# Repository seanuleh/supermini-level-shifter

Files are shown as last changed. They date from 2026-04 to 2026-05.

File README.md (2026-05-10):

# Hyper Level Shifter

A simple through-hole PCB that pairs an ESP32-S3 Super Mini with a SN74AHCT125N quad bus buffer to shift 3.3V GPIO signals up to 5V logic — designed for driving WS2812B/SK6812 LED strips with [Hyperk](https://github.com/awawa-dev/Hyperk) / [HyperHDR](https://github.com/awawa-dev/HyperHDR) ambilight setups.

<table><tr>
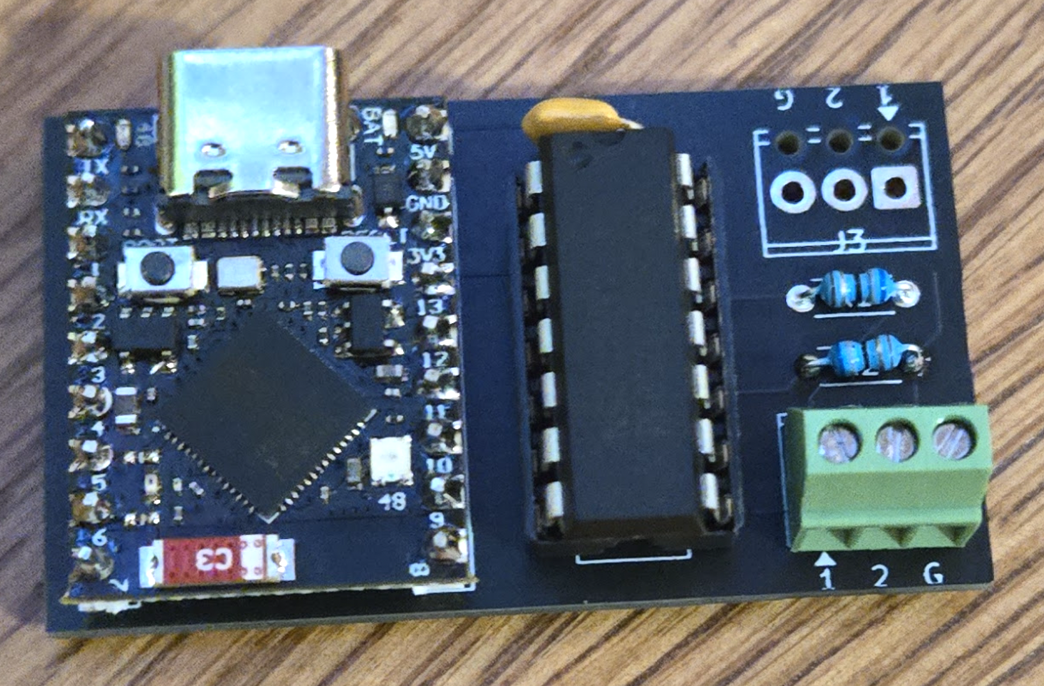
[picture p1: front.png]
PCB Front
<td></td>
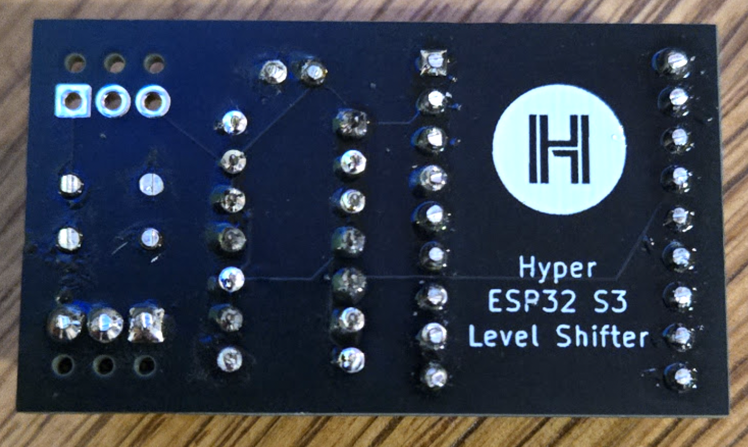
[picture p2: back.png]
PCB Back
<td></td>
</tr><tr>
<td align="center">Front</td>
<td align="center">Back</td>
</tr></table>

**[Download Gerbers (ZIP)](https://github.com/seanuleh/supermini-level-shifter/raw/main/manufacturing/default/default.gerber.zip)** — ready for JLCPCB / PCBWay (order bare PCB only)

## Features

- Socket for ESP32-S3 Super Mini (2× 1×9 female 2.54mm headers)
- DIP-14 socket for SN74AHCT125N logic level shifter (3.3V → 5V)
- Dual 3-pin 2.54mm screw terminals (top + bottom — choose whichever orientation suits your wiring)
- 68Ω series resistors on data outputs for signal integrity
- 100nF decoupling capacitor on IC VCC
- All through-hole components — no SMD soldering required

## Screw Terminal Pinout

Both terminals are electrically identical:

| Pin | Signal | Description |
|-----|---|---|
| 1 | DATA1  | GP1 level-shifted (5V logic) — LED segment 1 |
| 2 | DATA2  | GP2 level-shifted (5V logic) — LED segment 2 |
| 3 | GND | Ground reference |

> Power (5V) for the LED strips should come from a dedicated 5V supply, not the ESP32.

## Signal Path

```
ESP32 GP1 (3.3V) → SN74AHCT125N 1A → 1Y → 68Ω → Terminal pin 1
ESP32 GP2 (3.3V) → SN74AHCT125N 2A → 2Y → 68Ω → Terminal pin 2
ESP32 GND ──────────────────────────────────────→ Terminal pin 3
ESP32 5V  ──────────────────────────────────────→ IC VCC (pin 14)
```

## BOM

All parts are hand-soldered. No JLCPCB assembly required — order the bare PCB only.

| Ref | Part | Notes |
|-----|---|---|
| J1, J2 | 1×9 female 2.54mm pin header | 2× required |
| U1 | SN74AHCT125N | DIP-14, e.g. LCSC C5907 |
| — | DIP-14 IC socket | Order separately |
| J3, J4 | 3-pin 2.54mm screw terminal | e.g. KF128-2.54-3P, Phoenix MPT-0.5/3-2.54 |
| R1, R2 | 68Ω 1/8W axial resistor | Any 62–100Ω 1/8W axial |
| C1 | 100nF ceramic disc capacitor | 50V, 2.5mm pitch |

## Assembly Notes

- Install the DIP-14 socket first, then insert the SN74AHCT125N IC into the socket
- ESP32-S3 Super Mini plugs into J1/J2 with USB-C port facing toward the "USB Port ↑" silkscreen label
- The decoupling cap (C1) is non-polarised — orientation doesn't matter
- LED strip power should come from a dedicated 5V PSU; the ESP32 5V pin cannot source enough current for a full TV ambilight run

## Project Structure

Built with [atopile](https://atopile.io) 0.15.x.

```
ato.yaml                        # Build config
elec/src/
  level_shifter.ato             # Top-level module
  esp32s3_super_mini.ato        # ESP32 socket module
  parts/
    Header1x9F/                 # 1×9 female header
    SN74AHCT125N/               # DIP-14 quad buffer
    ScrewTerminal_2.54_3P/      # 3-pin screw terminal
    Resistor_TH_68R/            # 68Ω axial resistor
    Capacitor_TH_100nF/         # 100nF ceramic disc cap
elec/layouts/default/           # KiCAD PCB layout
```

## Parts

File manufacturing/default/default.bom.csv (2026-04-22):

Designator | Footprint | Quantity | Value | Manufacturer | Partnumber | LCSC Part #
C1 | Capacitor_TH_100nF:C_Disc_D3.0mm_W1.6mm_P2.50mm | 1 |  | Generic | C_100nF_TH_50V | CNONE_C100NF_TH
J1, J2 | Header1x9F:PinSocket_1x09_P2.54mm_Vertical | 2 |  | Generic | PinSocket_1x09_2.54mm | CNONE_HDR1X9F
J3, J4 | ScrewTerminal_2.54_3P:TerminalBlock_Phoenix_MPT-0,5-3-2.54_1x03_P2.54mm_Horizontal | 2 |  | Generic | ScrewTerminal_2.54mm_3P | CNONE_SCREW3P254
R1, R2 | Resistor_TH_68R:R_Axial_DIN0204_L3.6mm_D1.6mm_P5.08mm_Horizontal | 2 |  | Generic | R_68R_TH_1/8W | CNONE_R68R_TH
U1 | SN74AHCT125N:DIP-14_W7.62mm | 1 |  | Texas Instruments | SN74AHCT125N | CNONE_SN74AHCT125N

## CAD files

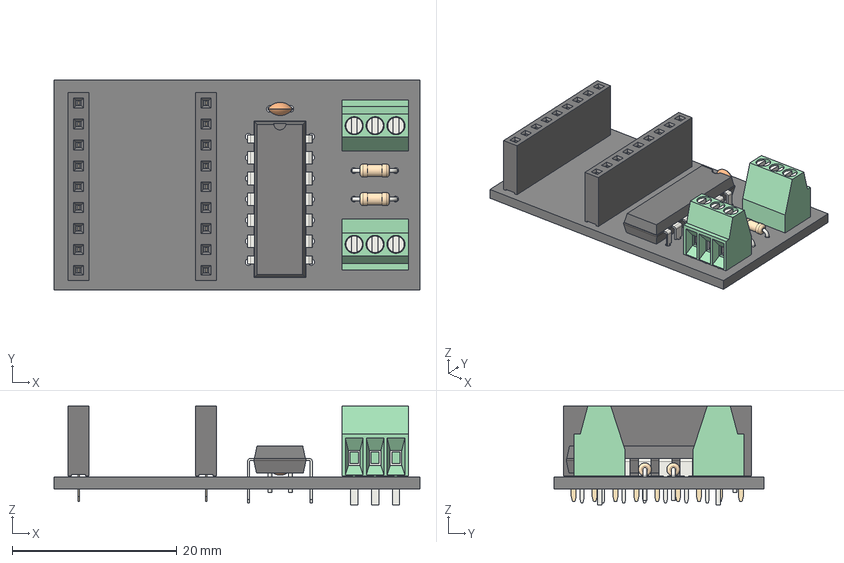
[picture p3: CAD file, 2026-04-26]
manufacturing/default/default.pcba.step
44.5 x 25.5 x 12.0 mm
DIP-14_W7.62mm
R_Axial_DIN0204_L3.6mm_D1.6mm_P5.08mm_Horizontal x 2
PinSocket_1x09_P2.54mm_Vertical x 2
TerminalBlock_Phoenix_MPT-0,5-3-2.54_1x03_P2.54mm_Horizontal x 2
C_Disc_D3.0mm_W1.6mm_P2.50mm
default_PCB

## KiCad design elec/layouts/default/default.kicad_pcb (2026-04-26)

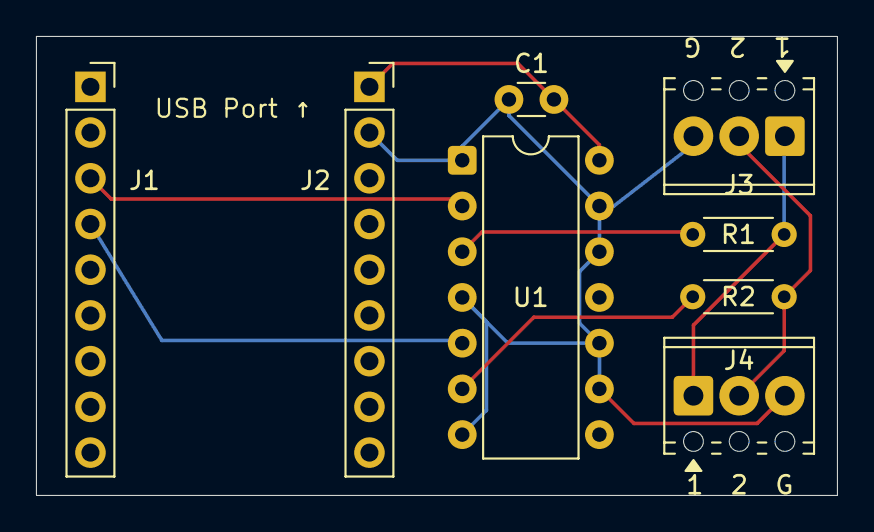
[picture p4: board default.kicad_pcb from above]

Board: 2 copper layers, 44.5 x 25.5 mm, 8 parts (0 on the bottom side), 8 nets.

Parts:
C1: C_Disc_D3.0mm_W1.6mm_P2.50mm
J1, J2: PinSocket_1x09_P2.54mm_Vertical
J3, J4: TerminalBlock_Phoenix_MPT-0,5-3-2.54_1x03_P2.54mm_Horizontal
R1, R2: R_Axial_DIN0204_L3.6mm_D1.6mm_P5.08mm_Horizontal
U1: DIP-14_W7.62mm

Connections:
1: R1.1, U1.3
1-1: R2.1, U1.6
1-2: J3.1, J4.1, R1.2
2: J1.3, U1.2
2-1: J3.2, J4.2, R2.2
3: C1.2, J2.2, J3.3, J4.3, U1.1, U1.4, U1.7, U1.9, U1.10, U1.12, U1.13
5: J1.4, U1.5
vcc_5v: C1.1, J2.1, U1.14

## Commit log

2026-04-22 Initial commit: ESP32-S3 Super Mini level shifter (signal-only variant)
    3.3V→5V logic level shifter for WS2812B/SK6812 LED strips.
    ESP32-S3 Super Mini socketed via 2x 1x9 female headers.
    SN74AHCT125N DIP-14 shifts GP1/GP2 signals.
    Dual 3-pin screw terminals (OUT1, OUT2, GND).
    Power for LED strips supplied externally.
    [default.bom.csv, default.jlcpcb_pick_and_place.csv, default.kicad_pcb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]
2026-04-26 PCB layout fixes, copper fill removal, and back silkscreen artwork
    - Fix ESP32 header spacing: J1/J2 corrected to 15.5mm center-to-center
    (was 18mm, which matched castellated pads not through-hole pin rows)
    - Shift J1/J2 right by 2.5mm to restore original gap to U1
    - Remove GND copper fill (both layers) to fix WiFi antenna detuning
    - Move J3/J4 screw terminals 1mm inward to clear silkscreen label overlap
    - Update CLAUDE.md with corrected header spacing notes
    - Add HyperHDR logo SVG (potrace-traced, evenodd fill) for B.SilkS import
    - Back silkscreen text: "Hyper / ESP32 S3 / Level Shifter" between headers
    [default.jlcpcb_pick_and_place.csv, default.kicad_pcb, default.pcba.step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]
2026-05-08 Add PCB render and gerber download link to README
2026-05-08 Show front and back PCB renders side by side in README
2026-05-08 Fix link case sensitivity in README.md
